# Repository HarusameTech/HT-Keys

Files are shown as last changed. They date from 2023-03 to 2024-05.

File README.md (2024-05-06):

# HT-Keys Public Repository

本リポジトリでは、_HT-Keys_ のファームウェアと開発者向け情報を公開しています

# HT-Keys とは

私 [Harusame](https://twitter.com/HarusameTech) が設計・制作している自作キーボードシリーズです

site：<https://www.harusame.tech/product/keyboard/HT-Keys/>  
購入
- HT-Keys-TKL
  - <https://harusametech.booth.pm/items/4568322>

# 製品シリーズ

## TKL

概要

- US 配列テンキーレス（87 キー）
- USB Type-C インターフェース採用
- CherryMX プロファイル
- RP2040 搭載 Raspberry Pi Pico 互換仕様
- ファームウェアレベルでカスタマイズ可能

## TK

概要

- 独自配列テンキー
- USB Type-C インターフェース採用
- CherryMX プロファイル
- RP2040 搭載 AE-RP2040 使用
- ファームウェアレベルでカスタマイズ可能

# Releases について

本リポジトリでは、以下のような命名規則を使用しています

| Releases の名前 | 意味 |
|:----|:----|
| `Developer Release` | HT-Keys のデバッグや開発用。主に開発者向け |
| `User Release - beta` | HT-Keys の開発段階のファームウェア。主に開発者向け |
| `User Release - Stable` | HT-Keys のファームウェア。使用者向け |

※ファームウェア開発を行うにあたり、何かしらのバグの解消ができたものを `beta` とし、開発時点で見つかっているバグをおおよそ、あるいは全て解消できたものを `Stable` としています

# ご使用の際の注意事項

本キーボードは US 配列です。そのため、Windows のキーボード設定を以下のように変更する必要があります

[設定] -> [言語と時刻] -> [言語] -> [優先する言語] の「オプション」から、ハードウェアキーボードレイアウトを変更してください


<div align="center">↓</div>

<div align="center">↓</div>


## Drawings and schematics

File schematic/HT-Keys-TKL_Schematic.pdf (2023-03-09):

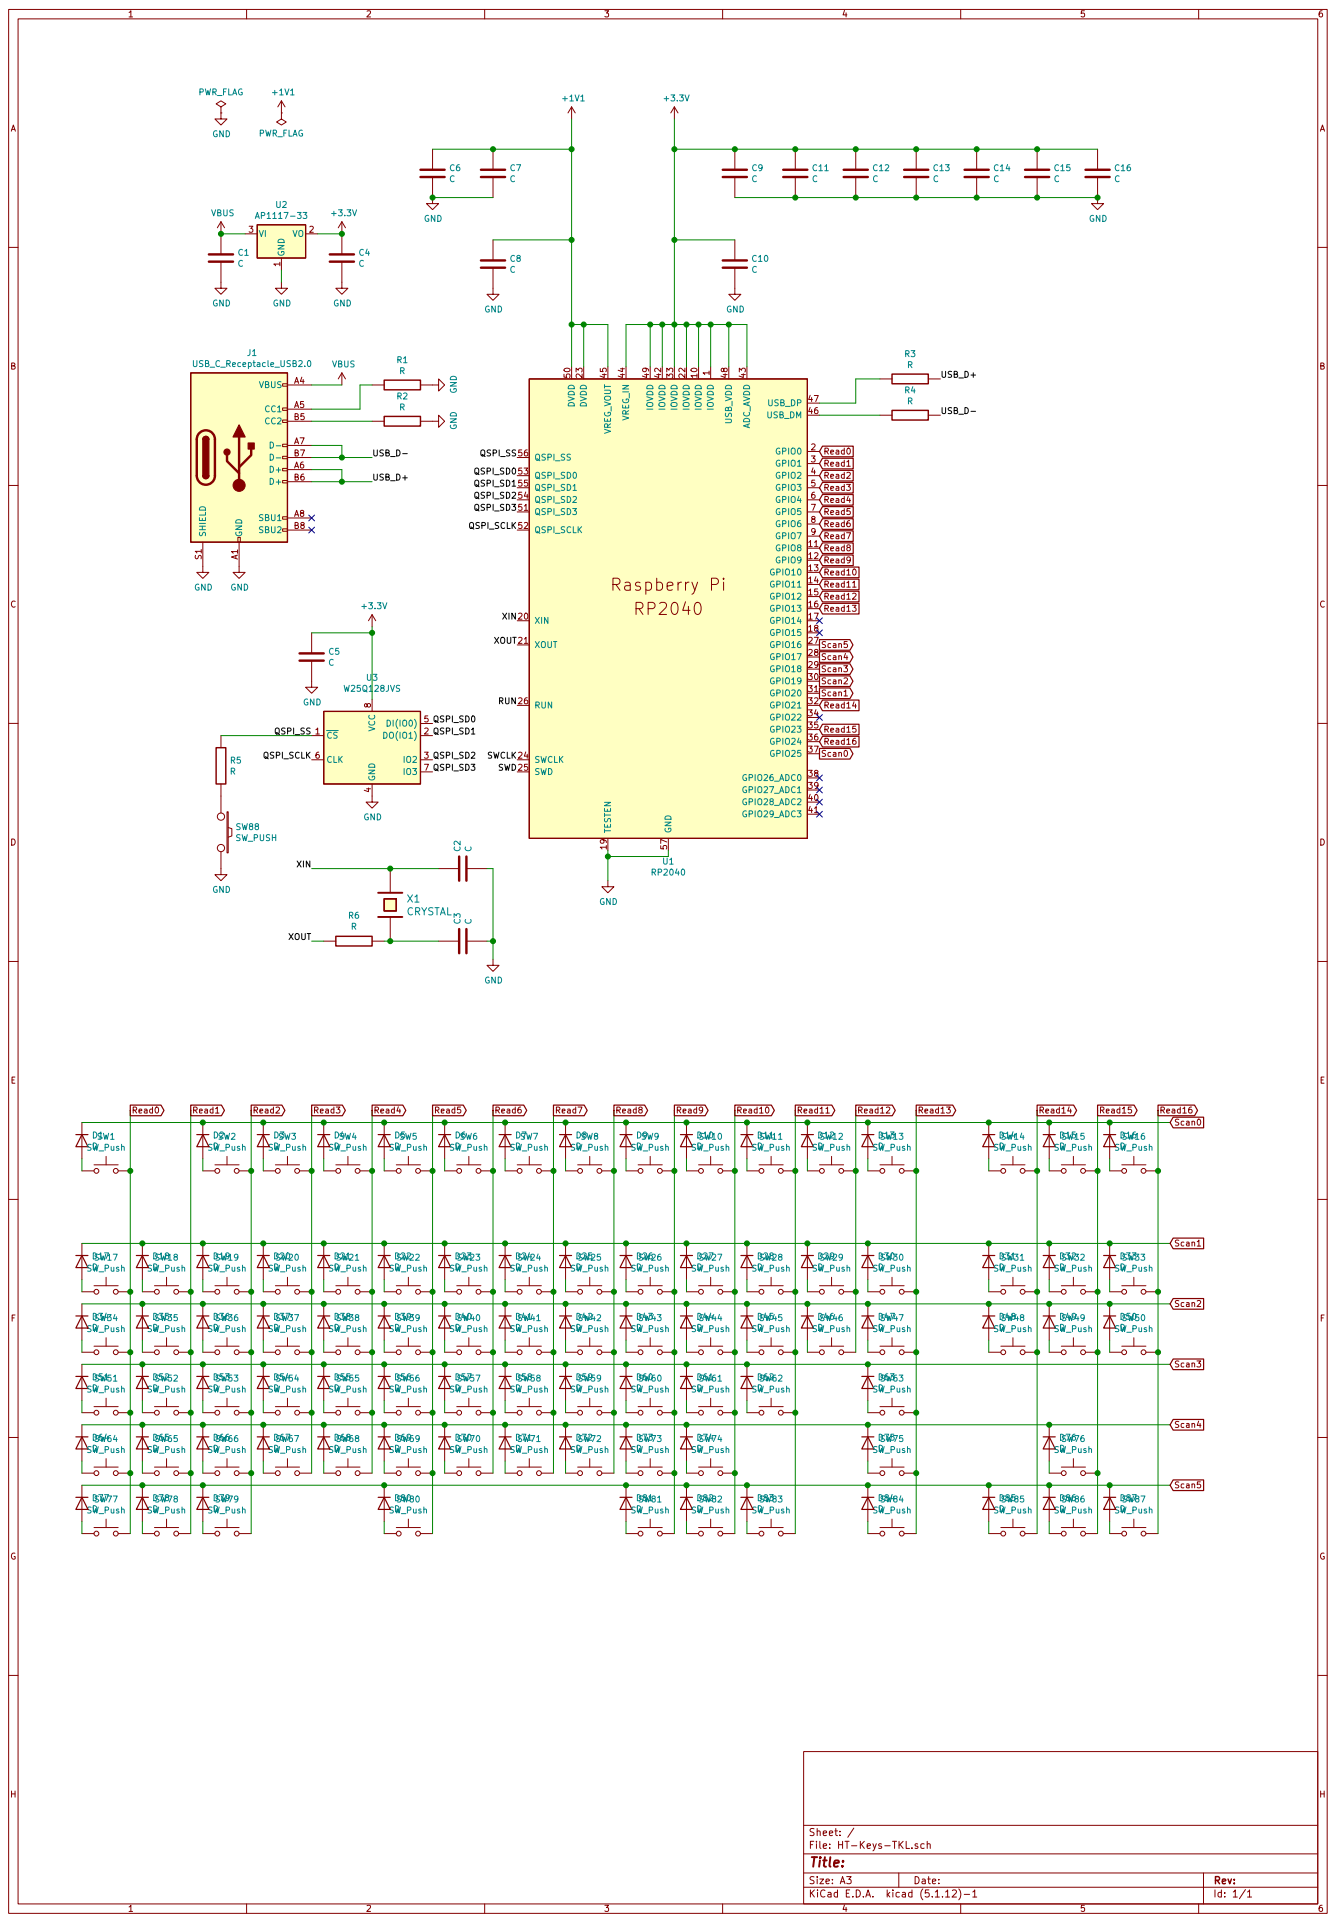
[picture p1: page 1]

1 IOVDD 10 GPIO8 11 GPIO9 12 GPIO10 13 GPIO11 14 GPIO12 15 GPIO13 16 GPIO14 17 GPIO15 18 TESTEN 19 GPIO0 2 XIN 20 XOUT 21 IOVDD 22 DVDD 23 SWCLK 24 SWD 25 RUN 26 GPIO16 27 GPIO17 28 GPIO18 29 GPIO1 3 GPIO19 30 GPIO20 31 GPIO21 32 IOVDD 33 GPIO22 34 GPIO23 35 GPIO24 36 GPIO25 37 GPIO26_ADC0 38 GPIO27_ADC1 39 GPIO2 4 GPIO28_ADC2 40 GPIO29_ADC3 41 IOVDD 42 ADC_AVDD 43 VREG_IN 44 VREG_VOUT 45 USB_DM 46 USB_DP 47 USB_VDD 48 IOVDD 49 GPIO3 5 DVDD 50 QSPI_SD3 51 QSPI_SCLK 52 QSPI_SD0 53 QSPI_SD2 54 QSPI_SD1 55 QSPI_SS 56 GND 57 GPIO4 6 GPIO5 7 GPIO6 8 GPIO7 9 U1 RP2040 SW73 SW_Push

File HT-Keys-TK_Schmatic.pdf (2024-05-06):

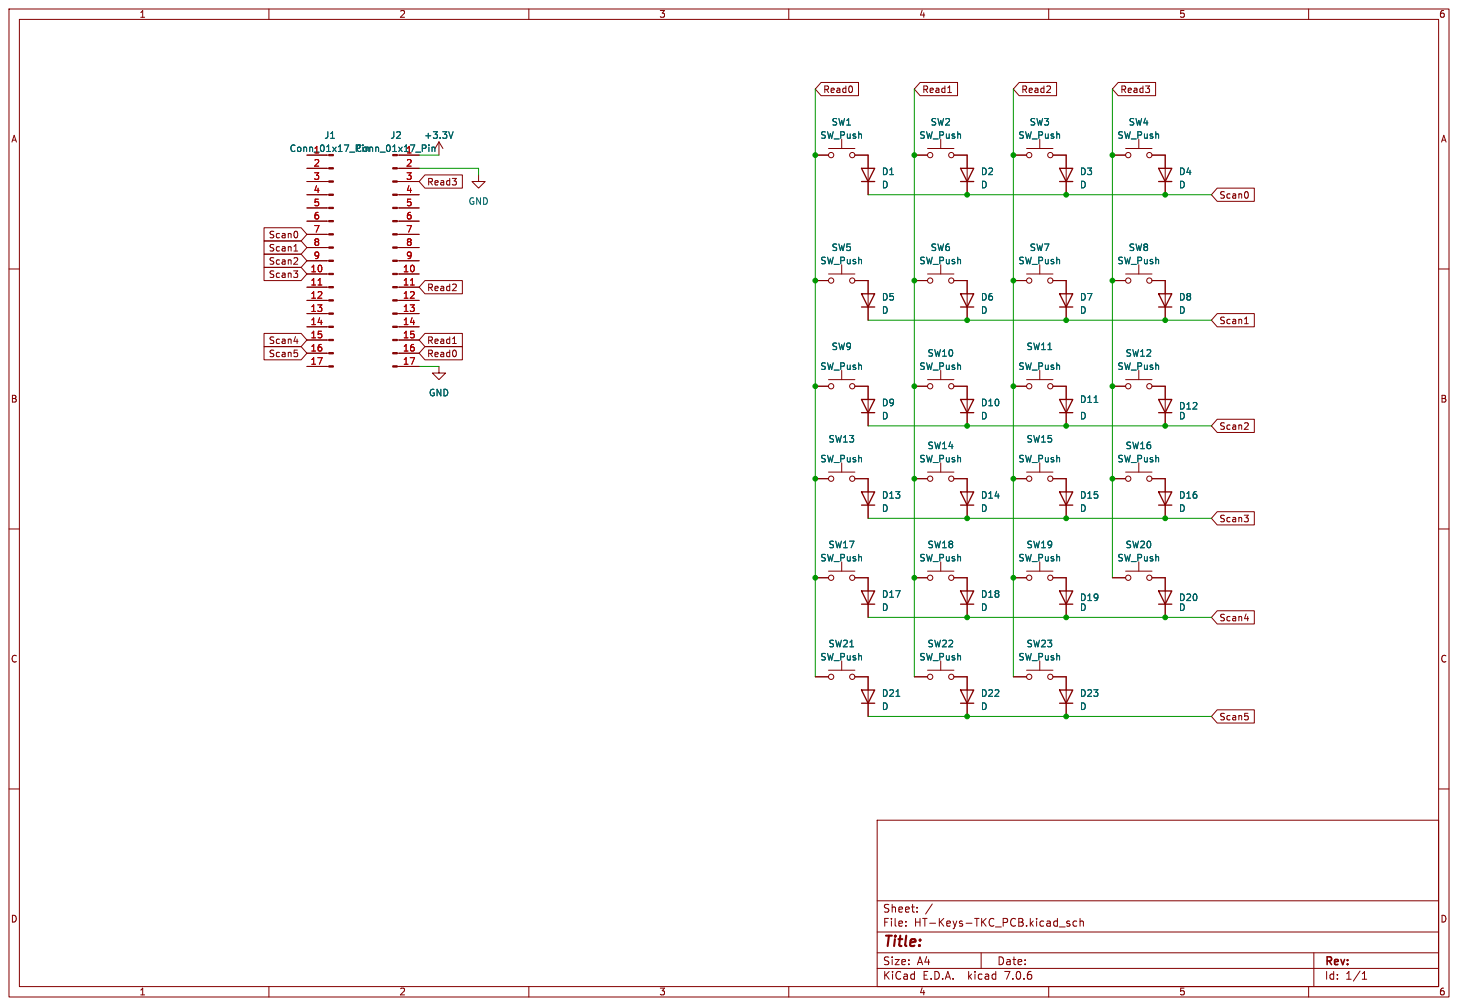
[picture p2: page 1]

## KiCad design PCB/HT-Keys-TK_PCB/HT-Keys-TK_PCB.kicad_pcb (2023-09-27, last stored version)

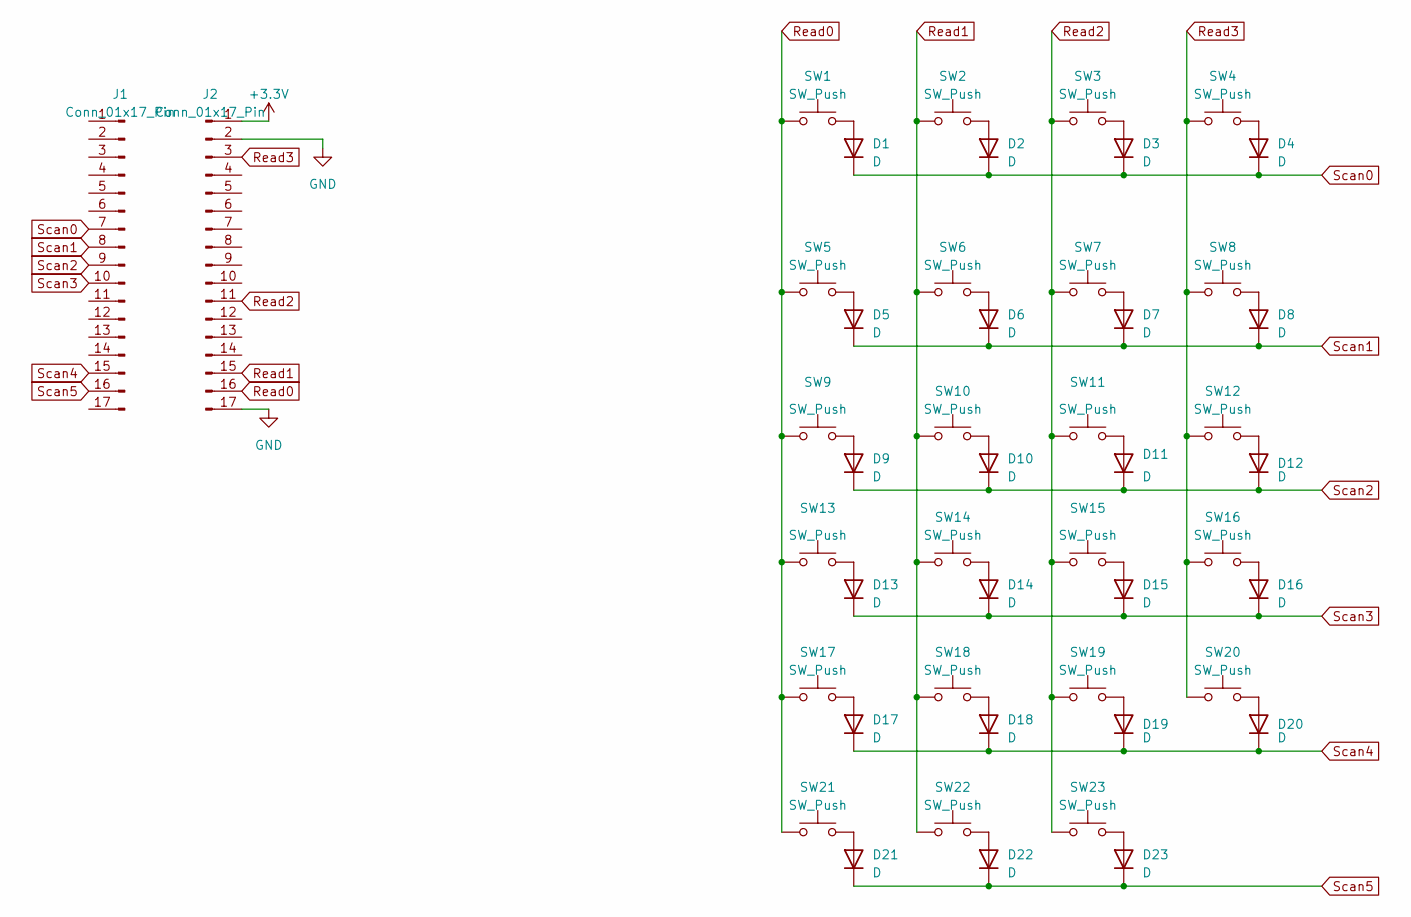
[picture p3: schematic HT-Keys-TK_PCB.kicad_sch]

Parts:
D1, D2, D3, D4, D5, D6, D7, D8, D9, D10, D11, D12, D13, D14, D15, D16, D17, D18, D19, D20, D21, D22, D23: D; D_A-405_P7.62mm_Horizontal
J1, J2: Conn_01x17_Pin; PinHeader_1x17_P2.54mm_Vertical
SW1, SW2, SW3, SW4, SW5, SW6, SW7, SW8, SW9, SW10, SW11, SW12, SW13, SW14, SW15, SW16, SW17, SW18, SW19, SW21, SW22, SW23: SW_Push; SW_Cherry_MX_1.00u_PCB
SW20: SW_Push; SW_Cherry_MX_2.00u_PCB

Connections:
+3.3V: J2.1
GND: J2.2, J2.17
unnamed: D1.2 (A), SW1.2
unnamed: D2.2 (A), SW2.2
unnamed: D3.2 (A), SW3.2
unnamed: D4.2 (A), SW4.2
unnamed: D5.2 (A), SW5.2
unnamed: D6.2 (A), SW6.2
unnamed: D7.2 (A), SW7.2
unnamed: D8.2 (A), SW8.2
unnamed: D9.2 (A), SW9.2
unnamed: D10.2 (A), SW10.2
unnamed: D11.2 (A), SW11.2
unnamed: D12.2 (A), SW12.2
unnamed: D13.2 (A), SW13.2
unnamed: D14.2 (A), SW14.2
unnamed: D15.2 (A), SW15.2
unnamed: D16.2 (A), SW16.2
unnamed: D17.2 (A), SW17.2
unnamed: D18.2 (A), SW18.2
unnamed: D19.2 (A), SW19.2
unnamed: D20.2 (A), SW20.2
unnamed: D21.2 (A), SW21.2
unnamed: D22.2 (A), SW22.2
unnamed: D23.2 (A), SW23.2
Read0: J2.16, SW1.1, SW5.1, SW9.1, SW13.1, SW17.1, SW21.1
Read1: J2.15, SW2.1, SW6.1, SW10.1, SW14.1, SW18.1, SW22.1
Read2: J2.11, SW3.1, SW7.1, SW11.1, SW15.1, SW19.1, SW23.1
Read3: J2.3, SW4.1, SW8.1, SW12.1, SW16.1, SW20.1
Scan0: D1.1 (K), D2.1 (K), D3.1 (K), D4.1 (K), J1.7
Scan1: D5.1 (K), D6.1 (K), D7.1 (K), D8.1 (K), J1.8
Scan2: D9.1 (K), D10.1 (K), D11.1 (K), D12.1 (K), J1.9
Scan3: D13.1 (K), D14.1 (K), D15.1 (K), D16.1 (K), J1.10
Scan4: D17.1 (K), D18.1 (K), D19.1 (K), D20.1 (K), J1.15
Scan5: D21.1 (K), D22.1 (K), D23.1 (K), J1.16

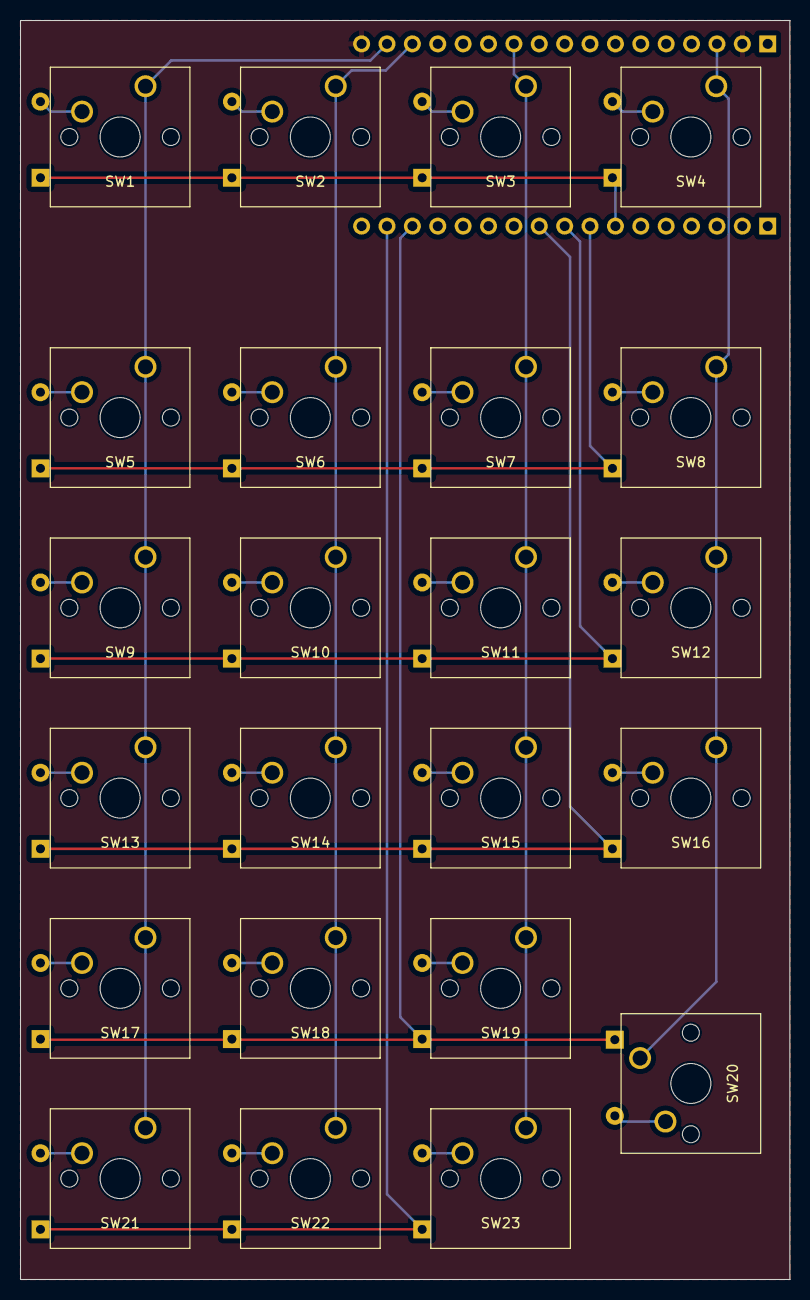
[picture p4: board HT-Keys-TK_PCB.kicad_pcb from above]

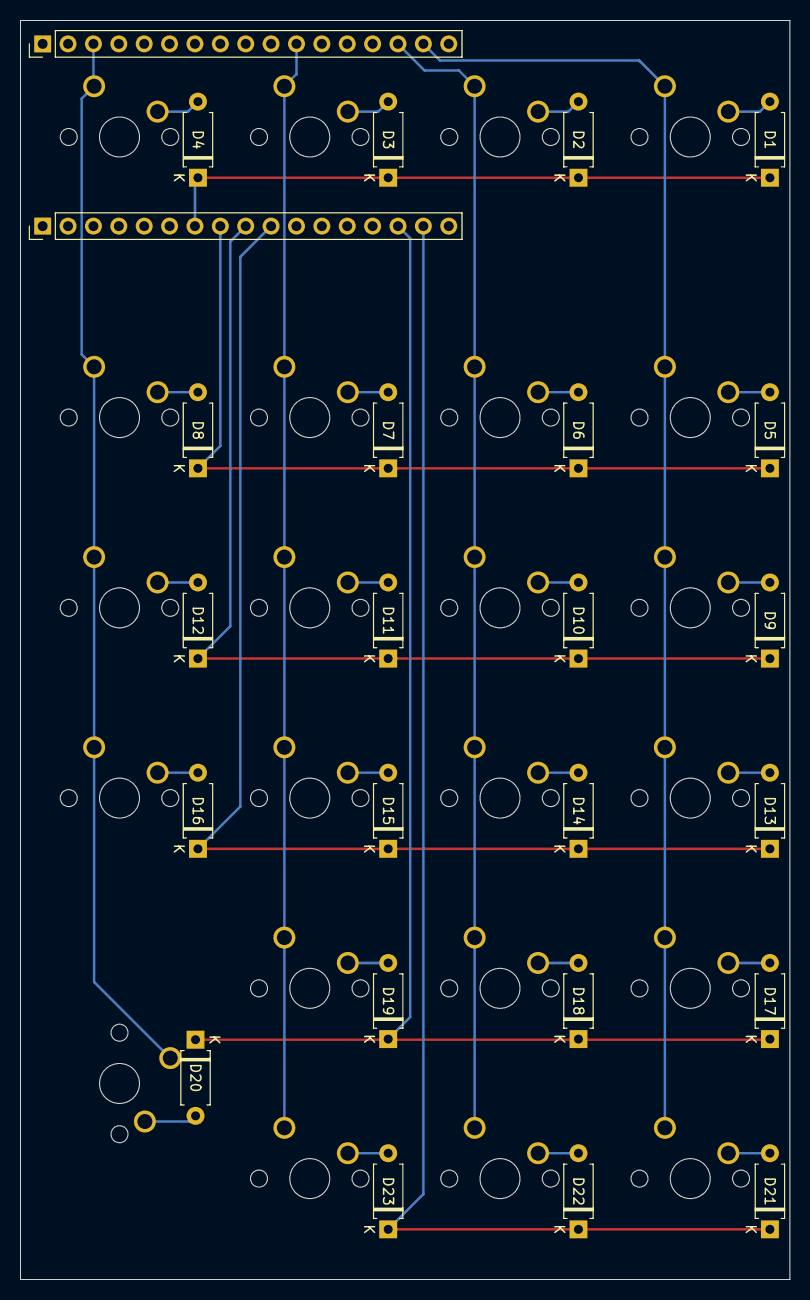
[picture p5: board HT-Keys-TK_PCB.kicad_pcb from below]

Board: 2 copper layers, 77.0 x 126.0 mm, 48 parts (25 on the bottom side), 34 nets.

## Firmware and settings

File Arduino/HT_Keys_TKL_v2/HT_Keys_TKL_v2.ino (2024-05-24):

#include "BleKeyboard.h"
#include "USB.h"
#include "USBHIDKeyboard.h"
#include <FastLED.h>

BleKeyboard blekbd;
USBHIDKeyboard usbkbd;

// キーマトリクスの処理の有効無効を指定:
// #define DEBUG_Matrix

// 実行速度モニタリングの有効無効を指定:
// #define DEBUG_Times

// キー出力を無効にする:
// #define DISABLE_KEYOUT

// LED を無効にする
#define DISABLE_LED

#ifdef DEBUG_Times
 #ifndef DEBUG
  #define DEBUG
 #endif
#endif

#ifdef DEBUG_Matrix
 #ifndef DEBUG
  #define DEBUG
 #endif
#endif

/* キー出力モードの指定用 */
#define MODE_Press true
#define MODE_Release false

/* 使用するGPIOを定義 */
#define Scan0 10
#define Scan1 11
#define Scan2 12
#define Scan3 9
#define Scan4 46
#define Scan5 3

#define Read0  42
#define Read1  41
#define Read2  40
#define Read3  39
#define Read4  38
#define Read5  37
#define Read6  36
#define Read7  35
#define Read8  45
#define Read9  48
#define Read10 47
#define Read11 21
#define Read12 14
#define Read13 13
#define Read14  8
#define Read15  2
#define Read16  1

#define MODE_SELECT  4
#define STATUS_LED   5
#define LED_OUTPUT   6

/* 各キースイッチとそれに割り当てるキーの対応を定義 */
#define SW1  Key_ESC
#define SW2  Key_F1
#define SW3  Key_F2
#define SW4  Key_F3
#define SW5  Key_F4
#define SW6  Key_F5
#define SW7  Key_F6
#define SW8  Key_F7
#define SW9  Key_F8
#define SW10 Key_F9
#define SW11 Key_F10
#define SW12 Key_F11
#define SW13 Key_F12
#define SW14 Key_PrintScrn
#define SW15 Key_ScrollLock
#define SW16 Key_Pause
#define SW17 Key_Tilde
#define SW18 Key_1
#define SW19 Key_2
#define SW20 Key_3
#define SW21 Key_4
#define SW22 Key_5
#define SW23 Key_6
#define SW24 Key_7
#define SW25 Key_8
#define SW26 Key_9
#define SW27 Key_0
#define SW28 Key_Hyphen
#define SW29 Key_Equal
#define SW30 Key_Backspace
#define SW31 Key_Insert
#define SW32 Key_Home
#define SW33 Key_PageUp
#define SW34 Key_Tab
#define SW35 Key_Q
#define SW36 Key_W
#define SW37 Key_E
#define SW38 Key_R
#define SW39 Key_T
#define SW40 Key_Y
#define SW41 Key_U
#define SW42 Key_I
#define SW43 Key_O
#define SW44 Key_P
#define SW45 Key_L_Bracket
#define SW46 Key_R_Bracket
#define SW47 Key_BackSlash
#define SW48 Key_Delete
#define SW49 Key_End
#define SW50 Key_PageDown
#define SW51 Key_CapsLock
#define SW52 Key_A
#define SW53 Key_S
#define SW54 Key_D
#define SW55 Key_F
#define SW56 Key_G
#define SW57 Key_H
#define SW58 Key_J
#define SW59 Key_K
#define SW60 Key_L
#define SW61 Key_SemiColon
#define SW62 Key_Quote
#define SW63 Key_Enter
#define SW64 Key_L_Shift
#define SW65 Key_Z
#define SW66 Key_X
#define SW67 Key_C
#define SW68 Key_V
#define SW69 Key_B
#define SW70 Key_N
#define SW71 Key_M
#define SW72 Key_camma
#define SW73 Key_period
#define SW74 Key_slash
#define SW75 Key_R_Shift
#define SW76 Key_UP
#define SW77 Key_L_Ctrl
#define SW78 Key_L_Win
#define SW79 Key_L_Alt
#define SW80 Key_Space
#define SW81 Key_R_Alt
#define SW83 Key_App
#define SW84 Key_R_Ctrl
#define SW85 Key_LT
#define SW86 Key_DN
#define SW87 Key_RT


/* キー名称とキーコードの対応を定義 */
#define Null            0x00
#define Key_ESC         0xB1
#define Key_F1          0xC2
#define Key_F2          0xC3
#define Key_F3          0xC4
#define Key_F4          0xC5
#define Key_F5          0xC6
#define Key_F6          0xC7
#define Key_F7          0xC8
#define Key_F8          0xC9
#define Key_F9          0xCA
#define Key_F10         0xCB
#define Key_F11         0xCC
#define Key_F12         0xCD
#define Key_PrintScrn   0xCE
#define Key_ScrollLock  0xCF
#define Key_Pause       0xD0
#define Key_Tilde       0x60
#define Key_1           0x31
#define Key_2           0x32
#define Key_3           0x33
#define Key_4           0x34
#define Key_5           0x35
#define Key_6           0x36
#define Key_7           0x37
#define Key_8           0x38
#define Key_9           0x39
#define Key_0           0x30
#define Key_Hyphen      0x2D
#define Key_Equal       0x3D
#define Key_Backspace   0xB2
#define Key_Insert      0xD1
#define Key_Home        0xD2
#define Key_PageUp      0xD3
#define Key_Tab         0xB3
#define Key_Q           0x71
#define Key_W           0x77
#define Key_E           0x65
#define Key_R           0x72
#define Key_T           0x74
#define Key_Y           0x79
#define Key_U           0x75
#define Key_I           0x69
#define Key_O           0x6F
#define Key_P           0x70
#define Key_L_Bracket   0x5B
#define Key_R_Bracket   0x5D
#define Key_BackSlash   0x5C
#define Key_Delete      0xD4
#define Key_End         0xD5
#define Key_PageDown    0xD6
#define Key_CapsLock    0xC1
#define Key_A           0x61
#define Key_S           0x73
#define Key_D           0x64
#define Key_F           0x66
#define Key_G           0x67
#define Key_H           0x68
#define Key_J           0x6A
#define Key_K           0x6B
#define Key_L           0x6C
#define Key_SemiColon   0x3B
#define Key_Quote       0x27
#define Key_Enter       0xB0
#define Key_L_Shift     0x81
#define Key_Z           0x7A
#define Key_X           0x78
#define Key_C           0x63
#define Key_V           0x76
#define Key_B           0x62
#define Key_N           0x6E
#define Key_M           0x6D
#define Key_camma       0x2C
#define Key_period      0x2E
#define Key_slash       0x2F
#define Key_R_Shift     0x85
#define Key_UP          0xDA
#define Key_L_Ctrl      0x80
#define Key_L_Win       0x83
#define Key_L_Alt       0x82
#define Key_Space       0x20
#define Key_R_Alt       0x86
#define Key_R_Win       0x87
#define Key_App         0xED
#define Key_R_Ctrl      0x84
#define Key_LT          0xD8
#define Key_DN          0xD9
#define Key_RT          0xD7

#define LED_COUNT   1
#define BLIGHTNESS 25

/* GPIO初期化用配列 */
const uint8_t Scan[] = {Scan0, Scan1, Scan2, Scan3, Scan4, Scan5 };
const uint8_t Read[] = {Read0, Read1, Read2, Read3, Read4, Read5, Read6, Read7, Read8, Read9, Read10, Read11, Read12, Read13, Read14, Read15, Read16};

/* キーマトリクス操作用配列 */
const uint8_t keyMap[sizeof(Scan)][sizeof(Read)] = {
  {SW1 , Null, SW2 , SW3 , SW4 , SW5 , SW6 , SW7 , SW8 , SW9 , SW10, SW11, SW12, SW13, SW14, SW15, SW16},
  {SW17, SW18, SW19, SW20, SW21, SW22, SW23, SW24, SW25, SW26, SW27, SW28, SW29, SW30, SW31, SW32, SW33},
  {SW34, SW35, SW36, SW37, SW38, SW39, SW40, SW41, SW42, SW43, SW44, SW45, SW46, SW47, SW48, SW49, SW50},
  {SW51, SW52, SW53, SW54, SW55, SW56, SW57, SW58, SW59, SW60, SW61, SW62, Null, SW63, Null, Null, Null},
  {SW64, SW65, SW66, SW67, SW68, SW69, SW70, SW71, SW72, SW73, SW74, Null, Null, SW75, Null, SW76, Null},
  {SW77, SW78, SW79, Null, Null, SW80, Null, Null, Null, SW81, NULL, SW83, Null, SW84, SW85, SW86, SW87}};

/* キーマトリクスの状態保存用配列 */
volatile uint8_t Matrix[sizeof(Scan)][sizeof(Read)];

#ifndef DISABLE_LED
  CRGB LED[LED_COUNT];
#endif

void setup() {
#ifdef DEBUG
  /* デバッグ用シリアル通信を115200bpsで開始 */
  Serial.begin(115200);
#endif

  /* 読み取り線を入力にしてプルアップ */
  for(size_t i = 0; i < sizeof(Read); i++) {
    pinMode(Read[i], INPUT_PULLUP);
  }

  /* スキャン線を出力にしてすべてHIGH */
  for(size_t i = 0; i < sizeof(Scan); i++) {
    pinMode(Scan[i], OUTPUT);
    digitalWrite(Scan[i], HIGH);
  }

  /* BLE / USB HID 切り替えスイッチ用入力 */
  pinMode(MODE_SELECT,  INPUT_PULLUP);
  pinMode(STATUS_LED , OUTPUT);

#ifndef DISABLE_LED
  /* ARGB LED の開始 */
  pinMode(LED_OUTPUT, OUTPUT);
  FastLED.addLeds<SK6812, LED_OUTPUT, GRB>(LED, LED_COUNT);//.setCorrection(TypicalLEDStrip);
  FastLED.setBrightness(BLIGHTNESS);
  LED_control(1);
#endif

#ifndef DISABLE_KEYOUT
  /* キーボードエミュレート開始 */
  usbkbd.begin();
  blekbd.begin();
  USB.begin();
#endif
}

void loop() {
  readKeyPad();  // キーボードの状態を読み取り、配列を更新する:
  checkMatrix();  // 配列を参照し押されたかどうかを判断:
  digitalWrite(STATUS_LED, digitalRead(MODE_SELECT));

  delayMicroseconds(1000000 / 1000);
}

void readKeyPad(void) {
  for(uint8_t i = 0; i < sizeof(Scan); i++) {     // スキャン線を順に切り替え:
    digitalWrite(Scan[i], LOW);                   // 読み取るところだけ落とす:
    delayMicroseconds(8);                         // ゴースト発生防止:
    for(uint8_t o = 0; o < sizeof(Read); o++) {   // 読み取って配列を更新:
      Matrix[i][o] = (Matrix[i][o] << 1) + (digitalRead(Read[o]) ? 0 : 1);
      delayMicroseconds(8);                       // ゴースト発生防止:
    }
    digitalWrite(Scan[i], HIGH);                  // 定常状態に戻す:
  }

#ifdef DEBUG_Matrix
  /* デバッグ表示 */
  for(uint8_t i = 0; i < sizeof(Scan); i++) {
    Serial.print(" | ");
    for(uint8_t o = 0; o < sizeof(Read); o++) {
      for(uint8_t b = 7; b > 0; b--) {            // 配列のデータを MSB から選択:
        if((Matrix[i][o] & 1 << b) == 0) {        // 配列のデータの対応するビットが 0 かどうかを判定:
          Serial.print("0");
        }else {
          Serial.print("1");
        }
      }
      Serial.print(" | ");
    }
    Serial.print("\n");
  }
  Serial.print("\n");
#endif
}

void checkMatrix(void) {
  /* キーボード出力 */
  for(uint8_t i = 0; i < sizeof(Scan); i++) {
    for(uint8_t o = 0; o < sizeof(Read); o++) {
      if((Matrix[i][o] & 0b00001111) == 0b00000011) {
        keyOut(keyMap[i][o], MODE_Press);
      }else if((Matrix[i][o] & 0b00000111) == 0b00000100) {
        keyOut(keyMap[i][o], MODE_Release);
      }
    }
  }

#ifndef DISABLE_LED
  static uint8_t LED_mode = 0;

  if((keyMap[5][10] & 0b00001111) == 0b1111) {
    if((keyMap[1][10] & 0b00001111) == 0b0011) {
      LED_mode = 0;
    }
    if((keyMap[1][9] & 0b00001111) == 0b0011) {
      LED_mode = 9;
    }
    if((keyMap[1][8] & 0b00001111) == 0b0011) {
      LED_mode = 8;
    }
    if((keyMap[1][7] & 0b00001111) == 0b0011) {
      LED_mode = 7;
    }
    if((keyMap[1][6] & 0b00001111) == 0b0011) {
      LED_mode = 6;
    }
    if((keyMap[1][5] & 0b00001111) == 0b0011) {
      LED_mode = 5;
    }
    if((keyMap[1][4] & 0b00001111) == 0b0011) {
      LED_mode = 4;
    }
    if((keyMap[1][3] & 0b00001111) == 0b0011) {
      LED_mode = 3;
    }
    if((keyMap[1][2] & 0b00001111) == 0b0011) {
      LED_mode = 2;
    }
    if((keyMap[1][1] & 0b00001111) == 0b0011) {
      LED_mode = 1;
    }
  }

  LED_control(LED_mode);
#endif
}

void keyOut(const uint8_t key, const bool mode) {
#ifndef DISABLE_KEYOUT
  if(key == 0) {
  }else {
    if(mode) {
      if(digitalRead(MODE_SELECT) == HIGH) {
        usbkbd.press(key);
      }else {
        blekbd.press(key);
      }
    }else {
      if(digitalRead(MODE_SELECT) == HIGH) {
        usbkbd.release(key);
      }else {
        blekbd.release(key);
      }
    }
  }
#endif
}

#ifndef DISABLE_LED
void LED_control(uint8_t mode) {
  FastLED.clearData();
  switch(mode) {
    case 0:
      for(uint8_t i = 0; i < LED_COUNT; i++) {
        LED[i] = CRGB::White;
      }
      FastLED.show();
      break;

    case 1:
      for(uint8_t i = 0; i < LED_COUNT; i++) {
        LED[i] = CRGB::Yellow;
      }
      FastLED.show();
      break;

    case 2:
      for(uint8_t i = 0; i < LED_COUNT; i++) {
        LED[i] = CRGB::Blue;
      }
      FastLED.show();
      break;

    case 3:
      for(uint8_t i = 0; i < LED_COUNT; i++) {
        LED[i] = CRGB::Green;
      }
      FastLED.show();
      break;

    case 4:
      for(uint8_t i = 0; i < LED_COUNT; i++) {
        LED[i] = CRGB::Red;
      }
      FastLED.show();
      break;

    default:
      break;
  }
}
#endif

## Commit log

2023-03-06 Update HT_Keys_TKL.ino
    バックスラッシュキー以外のキーコードの特定が完了
2023-03-07 Update HT_Keys_TKL.ino
    US 配列を明示するように変更
    大文字が入力されていたので小文字になるように `0x20` を引くように変更
    バージョン番号をコード内に追加
2023-03-09 Add files via upload
    回路図の PDF ファイルを追加
2023-07-07 シフトキーのキーコードを修正
2023-07-08 シフトキーを入れ替え
2023-07-15 不要なルーチンを削除
2023-07-15 キーリリースの判断条件を変更
2023-07-15 入れ替えてたシフトキーを戻した
2023-07-15 キーリリースの条件変更
2023-07-15 割り当てる文字コードを間違えていたので修正
2023-09-14 v2 のファイルを作成
2023-09-14 動作見直し
2023-09-15 コードを整形
2023-09-16 コメントを追加
2023-09-17 コメントを編集
2023-09-27 HT-Keys-TK 基板 v1
    [HT-Keys-TK_PCB-B_Cu.gbr, HT-Keys-TK_PCB-B_Mask.gbr, HT-Keys-TK_PCB-B_Paste.gbr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]
2023-09-27 HT_Keys_TK PCB v1
    [HT-Keys-TK_PCB.kicad_pcb, HT-Keys-TK_PCB.kicad_sch]
2023-09-29 add schematic pdf
2024-05-07 ステータス表示を追加
2024-05-07 ピンアサイン更新
